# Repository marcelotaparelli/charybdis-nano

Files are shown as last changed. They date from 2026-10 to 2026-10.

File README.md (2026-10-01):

# Charybdis Nano 3x5 — documentação da build

Este repositório registra a construção completa de um Charybdis Nano 3x5: arquivos de impressão, arquitetura eletrônica, compras, montagem e configuração. A build é handwire, usa dois RP2040-Zero e QMK, e terá trackball óptico PMW3360 de 34 mm.

## Fluxo da build

**IMPRIMIR → COMPRAR → SOLDAR → MONTAR → CONFIGURAR QMK → USAR**

## Estrutura

- `01_cases/` — cases das duas metades.
- `02_bottom_plates/` — placas inferiores.
- `03_trackball/` — peças do conjunto da trackball.
- `04_tenting/` — peças para inclinação.
- `05_keycaps/` — coupon e conjunto de keycaps.
- `06_electronics/` — arquitetura, BOM, PCB do sensor e registro de compras.

> **Atenção:** os arquivos `LEFT` já estão espelhados. **Não espelhe novamente no slicer.** Há 11 modelos de impressão atualmente no repositório.

## Keycaps

O procedimento recomendado para builds em geral continua sendo imprimir primeiro `05_keycaps/MX_stem_fit_coupon.stl`, testar em um switch MX e só então imprimir `05_keycaps/full_set_35.3mf`.

Nesta build, Marcelo decidiu conscientemente imprimir o conjunto completo de uma vez porque o custo total da impressão é baixo. Se o encaixe exigir, os keycaps serão recalibrados e reimpressos. Essa é uma decisão específica desta build, não uma mudança na recomendação geral.

O conjunto tem quatro perfis ergonômicos, que não devem ser tratados como um único perfil: 10 top, 10 home, 10 bottom e 5 thumb.

## Eletrônica e andamento

A pasta [`06_electronics/`](06_electronics/README.md) documenta a arquitetura escolhida, a BOM viva, a placa PMW3360 rev 2.0c e os gastos confirmados. A ligação entre as metades ainda é uma hipótese: protocolo QMK split, pinout e quantidade de condutores precisam ser validados antes da soldagem final.

## Licenças

Créditos, origens conhecidas e termos das geometrias de terceiros estão em [`THIRD_PARTY_LICENSES.md`](THIRD_PARTY_LICENSES.md). As licenças aplicáveis continuam válidas.

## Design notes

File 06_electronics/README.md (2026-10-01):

# Eletrônica — Charybdis Nano 3x5

## Arquitetura escolhida

- Charybdis Nano 3x5, handwire, com switches MX e diodos through-hole 1N4148.
- Dois controladores RP2040-Zero com USB-C, um por metade, usando QMK.
- Sensor óptico PMW3360DM-T2QU com lente LM19-LSI e trackball de 34 mm.
- Três rolamentos MR63ZZ de 3 × 6 × 2,5 mm.
- Sem RGB, key flex PCBs, thumb flex PCB, Splinky ou Splinktegrated.

O handwire foi escolhido para dispensar PCBs flexíveis de matriz e permitir a montagem direta dos switches, diodos e controladores. A placa dedicada do sensor PMW3360 continua sendo usada. O pedido de fabricação dessa placa e sua montagem SMD estão descritos em [trackball-pcb.md](trackball-pcb.md).

## Controladores

São usados dois RP2040-Zero USB-C, um em cada metade. O holder do RP2040-Zero ainda não está resolvido; nenhum STL de holder foi definido. Antes de desenhar ou fabricar um adaptador, devem ser validados:

1. Dimensões reais do RP2040-Zero recebido.
2. Espaço interno disponível nos cases.
3. Pontos de montagem existentes.
4. Acesso e orientação do USB-C.
5. Folga para fios e solda.

A preferência futura é por um pequeno holder/adaptador independente, sem modificar os STLs originais dos cases.

## Ligação entre as metades

A intenção atual é evitar TRRS na primeira build e usar uma ligação fixa simples. **VCC + GND + DATA é apenas uma hipótese atual, não uma solução elétrica fechada ou validada.** O protocolo QMK split, o pinout e a quantidade de condutores ainda precisam ser definidos e validados antes da soldagem final. A interligação entre as metades ainda não foi testada eletricamente.

## Próximas etapas físicas

1. Receber e inspecionar a impressão.
2. Comprar os componentes restantes.
3. Receber as PCBs PMW3360.
4. Validar os encaixes.
5. Resolver o holder do RP2040-Zero.
6. Fazer o handwire da matriz.
7. Montar o sensor e a trackball.
8. Configurar QMK.

Consulte a [BOM viva](bom.md) para itens e status e o [registro de compras](purchases.md) para valores efetivamente pagos.

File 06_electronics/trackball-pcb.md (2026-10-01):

# PCB da trackball — PMW3360 rev 2.0c

## Projeto e arquivos usados

Projeto oficial: [BastardKB/charybdis-pmw-3360-sensor-pcb](https://github.com/Bastardkb/charybdis-pmw-3360-sensor-pcb)

Release correta: [2.0c](https://github.com/Bastardkb/charybdis-pmw-3360-sensor-pcb/releases/tag/2.0c)

Arquivos exatos utilizados no pedido:

- Gerber: [`sensor_2.0c.zip`](https://github.com/Bastardkb/charybdis-pmw-3360-sensor-pcb/releases/download/2.0c/sensor_2.0c.zip)
- BOM: [`bom.csv`](https://github.com/Bastardkb/charybdis-pmw-3360-sensor-pcb/releases/download/2.0c/bom.csv)
- Positions/CPL: [`positions.csv`](https://github.com/Bastardkb/charybdis-pmw-3360-sensor-pcb/releases/download/2.0c/positions.csv)

Os arquivos de fabricação não foram copiados para este repositório; use os assets da release oficial indicada.

## Alerta sobre o Gerber

**Não use como Gerber desta build `sensor/jlcpcb/production_files/GERBER-sensor.zip`.** Durante a preparação do pedido, esse pacote antigo foi conferido e renderizava **REV 1.8**. Com o BOM/CPL 2.0c, os componentes apareciam visualmente deslocados. O pedido foi interrompido antes da fabricação. A correção foi usar o asset `sensor_2.0c.zip` da release oficial 2.0c.

Antes de pagar, o preview final do pedido com o Gerber correto foi revisado; os overlays dos componentes estavam alinhados com os pads.

## Configuração registrada do pedido JLCPCB

**PCB**

- FR-4, 2 layers, espessura 1,6 mm, cobre 1 oz.
- Máscara verde e serigrafia branca.
- HASL.
- Quantidade: 5 PCBs.

**PCBA**

- Economic PCBA, Bottom Side.
- Quantidade: 2 placas montadas.
- Parts Selection / Self-Service.
- A montagem automática inclui os componentes SMD selecionados no BOM/CPL.

Itens deliberadamente fora da montagem de fábrica:

- **U1001 — PMW3360DM-T2QU:** será comprado e montado separadamente; não incluso na PCBA.
- **J1001 — header 1 × 06, 2,54 mm:** não precisa ser montado pela fábrica.
- **J1002 — conector FPC:** não selecionado, pois a build é handwire e não usa o flex correspondente.
- **LM19-LSI:** lente óptica/mecânica, será comprada separadamente.

O pedido foi pago. Valores finais e totais por moeda estão em [purchases.md](purchases.md).

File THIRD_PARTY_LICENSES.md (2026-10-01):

# Atribuição e licenças de terceiros

Este pacote reúne geometrias de terceiros e versões espelhadas. Os créditos e termos dos projetos de origem continuam aplicáveis.

## Charybdis

- Projeto: [BastardKB/Charybdis](https://github.com/Bastardkb/Charybdis)
- Licença: CC BY-NC-SA 4.0

Arquivos originados ou derivados desse projeto:

- `01_cases/RIGHT_charybdisnano_v2_v187.stl`
- `02_bottom_plates/RIGHT_alien_v2_185.stl`
- `03_trackball/adapter_v2_top_v75.stl`
- `03_trackball/adapter_v4_bottom_v17.stl`
- `03_trackball/sensor_cover_v51.stl`
- `04_tenting/RIGHT_tent15deg_v2_27.stl`
- `04_tenting/LEFT_tent15deg_v2_27.stl` — versão espelhada no eixo X do tent correspondente.

## Skeletyl

- Projeto: [BastardKB/Skeletyl](https://github.com/Bastardkb/Skeletyl)
- Licença: CC BY-NC-SA 4.0

Arquivos originados ou derivados desse projeto:

- `01_cases/LEFT_case_v4_103.stl` — versão espelhada no eixo X da geometria Skeletyl V4 correspondente.
- `02_bottom_plates/LEFT_plate_v4_103.stl` — versão espelhada no eixo X da geometria Skeletyl V4 correspondente.

Não há reivindicação de autoria sobre as geometrias originais. Os termos de uso não comercial (NC) e compartilhamento pela mesma licença (SA) continuam aplicáveis às derivações.

## DES / PseudoMakeMeKeyCapProfiles

- Projeto: [pseudoku/PseudoMakeMeKeyCapProfiles](https://github.com/pseudoku/PseudoMakeMeKeyCapProfiles)
- Licença: GPL-3.0

Arquivos relacionados:

- `05_keycaps/MX_stem_fit_coupon.stl`
- `05_keycaps/full_set_35.3mf`
- `05_keycaps/source/des_compatible_keycaps.scad`
- `05_keycaps/source/mx_stem_fit_coupon.scad`
- `05_keycaps/source/plates.scad`

Texto da licença em `LICENSES/GPL-3.0.txt`.

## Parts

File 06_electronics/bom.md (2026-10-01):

# BOM — lista de materiais viva

Os status e preços abaixo registram apenas informações confirmadas. “A comprar” indica que não há compra confirmada nesta documentação; preço e fornecedor permanecem em aberto.

| Peça | Modelo / especificação | Qtd. | Status | Preço pago | Fornecedor / link |
|---|---|---:|---|---:|---|
| Controlador | RP2040-Zero USB-C | 2× | Comprado | R$ 55,76 total pago | [WJ Componentes](https://www.wjcomponentes.com.br/placa-desenvolvimento-rp2040-zero-usb-c) |
| Switches | Outemu Red, MX, linear | 40 comprados; 35 usados + 5 reservas | Comprado | R$ 89,99 | Mercado Livre |
| Diodos | 1N4148, axial / through-hole, DO-35 | 100 comprados; ~35 usados + restante reserva | Comprado | R$ 20,00 | Mercado Livre |
| Sensor | PMW3360DM-T2QU | 1 | Comprado | R$ 91,75 total do conjunto | AliExpress |
| Lente | LM19-LSI | 1 | Comprada | Incluída no conjunto (total na linha do sensor) | AliExpress |
| PCB do sensor | BastardKB PMW3360, rev 2.0c | 5 fabricadas; 2 com PCBA | Comprado; pedido pago | US$ 23.54 (pedido inteiro; não é preço unitário) | [Release oficial 2.0c](https://github.com/Bastardkb/charybdis-pmw-3360-sensor-pcb/releases/tag/2.0c); JLCPCB |
| Fio para handwire | 28 AWG / aproximadamente 0,10 mm² | 1 rolo | Comprado | R$ 50,96 | Mercado Livre |
| Cabo | USB-C com dados | A definir | A comprar | — | A definir |
| Trackball | Esfera de 34 mm, compatível com Logitech M570/M575 | 1 | Comprado | R$ 94,00 total | Mercado Livre |
| Rolamentos | MR63ZZ, 3 × 6 × 2,5 mm | 4 comprados; 3 usados + 1 reserva | Comprado | R$ 54,96 total (produto R$ 47,90) | [Mercado Livre](https://www.mercadolivre.com.br/4-rolamentos-mr63zz-3mm--6mm--25mm-micro-rolamento/up/MLBU597514219) |
| Parafusos | M4 × 8 | 12 | A comprar | — | A definir |
| Insertos | M4 × D6,0 × L5,0 | 12 | A comprar | — | A definir |
| Parafusos | M3 × 8 | 8 | A comprar | — | A definir |
| Insertos | M3 × D5 × L5 | 5 | A comprar | — | A definir |
| Pés | Pés de borracha, opcionais | A definir | A comprar (opcional) | — | A definir |

## Ferramentas, caso ainda não estejam disponíveis

| Ferramenta | Qtd. | Status | Preço pago | Fornecedor / link |
|---|---:|---|---:|---|
| Ferro de solda | 1 | Verificar disponibilidade | — | A definir |
| Suporte para ferro | 1 | Verificar disponibilidade | — | A definir |
| Solda | A definir | Verificar disponibilidade | — | A definir |
| Fluxo | A definir | Verificar disponibilidade | — | A definir |
| Multímetro com continuidade | 1 | Verificar disponibilidade | — | A definir |
| Alicate de corte rente | 1 | Verificar disponibilidade | — | A definir |
| Pinça | 1 | Verificar disponibilidade | — | A definir |
| Sugador de solda | 1 | Recomendado; verificar disponibilidade | — | A definir |

Os componentes SMD definidos no BOM/CPL usados no pedido da placa foram selecionados para montagem pela fábrica nas duas PCBs. O sensor U1001, a lente e os conectores excluídos dessa montagem estão discriminados em [trackball-pcb.md](trackball-pcb.md).

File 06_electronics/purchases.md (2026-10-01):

# Registro de compras e custos

Este registro contém valores informados como efetivamente pagos ou contratados. Totais são mantidos separados por moeda; não há conversão de USD para BRL porque a conversão efetivamente aplicada na cobrança não está registrada.

## Compra 1 — impressão

- **Data:** 2026-10-01
- **Fornecedor:** Nutss
- **Site:** [nutss3d.com.br](https://nutss3d.com.br/)
- **Escopo:** impressão de todo o projeto, incluindo keycaps em resina.
- **Valor combinado/pago:** R$ 195,00.
- **Status:** contratado; produção pendente ou iniciando.

Marcelo decidiu, como exceção consciente desta build, imprimir o conjunto completo de keycaps antes de validar o coupon. O custo total da impressão é baixo para esta build e, se o encaixe exigir, os keycaps serão recalibrados e reimpressos. Isso não altera o procedimento recomendado geral: imprimir e testar o coupon MX antes do conjunto completo.

## Compra 2 — JLCPCB

- **Status:** pago.
- **Item:** PCB do sensor PMW3360 rev 2.0c.
- **Quantidade:** 5 PCBs; PCBA Bottom Side em 2 placas.
- **Serviço de envio:** Global Standard Direct Line.
- **Merchandise Total:** US$ 12.13.
- **Shipping:** US$ 11.41.
- **Order Total pago:** **US$ 23.54**.

US$ 22.13 não é o valor pago: houve desconto antes do fechamento do pedido. A composição e as exclusões da montagem estão em [trackball-pcb.md](trackball-pcb.md).

## Compra 3 — rolamentos MR63ZZ

- **Data:** 2026-10-01
- **Fornecedor:** Mercado Livre
- **Item:** 4× MR63ZZ, 3 × 6 × 2,5 mm.
- **Uso:** 3 necessários + 1 reserva.
- **Produto:** R$ 47,90.
- **Frete:** grátis.
- **Total informado/pago:** R$ 54,96.
- **Status:** comprado.
- **Anúncio:** [4 rolamentos MR63ZZ](https://www.mercadolivre.com.br/4-rolamentos-mr63zz-3mm--6mm--25mm-micro-rolamento/up/MLBU597514219).

## Compra 4 — esfera do trackball

- **Data:** 2026-10-01
- **Fornecedor:** Mercado Livre
- **Item:** esfera de trackball de 34 mm, compatível com Logitech M570/M575.
- **Produto:** R$ 54,03.
- **Frete:** R$ 23,99.
- **Impostos:** R$ 15,98.
- **Total pago:** R$ 94,00.
- **Status:** comprado.

## Compra 5 — sensor PMW3360DM-T2QU + lente LM19-LSI

- **Data:** 2026-10-01
- **Fornecedor:** AliExpress
- **Itens:** PMW3360DM-T2QU e lente LM19-LSI, vendidos como conjunto.
- **Subtotal:** R$ 48,99.
- **Frete:** R$ 27,12.
- **Imposto de importação:** R$ 0,00.
- **ICMS:** R$ 15,64.
- **Total pago:** R$ 91,75.
- **Status:** pago/comprado.

O valor de R$ 91,75 corresponde ao conjunto e não está dividido entre sensor e lente.

## Compra 6 — controladoras RP2040-Zero

- **Data:** 2026-10-01
- **Fornecedor:** WJ Componentes Eletrônicos
- **Item:** RP2040-Zero USB-C.
- **Quantidade:** 2.
- **Preço nominal por unidade:** R$ 23,51.
- **Subtotal dos produtos:** R$ 47,02.
- **Frete:** Sedex Correios, R$ 10,15.
- **Total normal do pedido:** R$ 57,17.
- **Total efetivamente pago no Pix com desconto:** R$ 55,76.
- **Status:** comprado/pago.
- **Produto:** [Placa de desenvolvimento RP2040 Zero USB-C](https://www.wjcomponentes.com.br/placa-desenvolvimento-rp2040-zero-usb-c).

## Compra 7 — switches Outemu Red

- **Data:** 2026-10-01
- **Fornecedor:** Mercado Livre
- **Item:** switches Outemu Red, padrão MX, tipo linear.
- **Quantidade:** 40.
- **Uso previsto:** 35 usados + 5 de reserva.
- **Valor pago:** R$ 89,99.
- **Frete:** grátis.
- **Status:** comprado/pago.

## Compra 8 — diodos 1N4148

- **Data:** 2026-10-01
- **Fornecedor:** Mercado Livre
- **Item:** diodos 1N4148, encapsulamento DO-35, axial / through-hole.
- **Quantidade:** 100.
- **Quantidade necessária para a build:** aproximadamente 35; restante para reserva.
- **Total efetivamente pago:** R$ 20,00.
- **Status:** comprado/pago.

## Compra 9 — fio para handwire

- **Data:** 2026-10-01
- **Fornecedor:** Mercado Livre
- **Item:** fio para handwire, bitola 28 AWG, seção aproximada de 0,10 mm².
- **Quantidade:** 1 rolo.
- **Total efetivamente pago:** R$ 50,96.
- **Status:** comprado/pago.

## Total acumulado confirmado

- **BRL:** R$ 652,42.
- **USD:** US$ 23.54.

Os montantes permanecem em moedas separadas. Não converter USD para BRL sem o valor efetivo da conversão aplicada na cobrança.

## Próximas compras

Consultar a [BOM](bom.md) para a relação atual de componentes, hardware e ferramentas a comprar ou verificar. Não há preço ou fornecedor confirmado para os itens ainda não adquiridos.

Para cada compra futura, registrar item exato, quantidade, preço pago, frete, fornecedor, link, data e status de entrega.

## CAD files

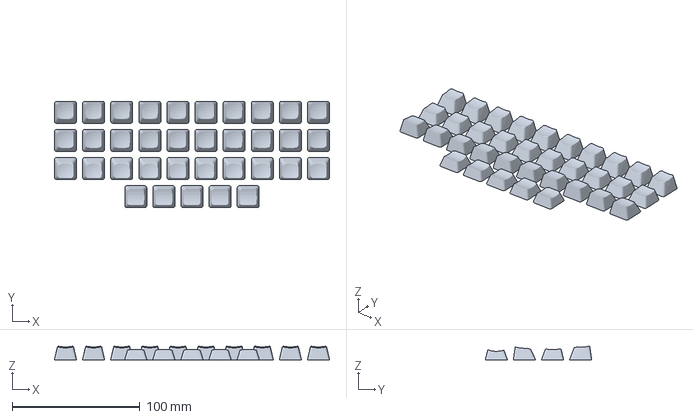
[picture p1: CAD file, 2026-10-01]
05_keycaps/full_set_35.3mf
215.2 x 83.2 x 10.6 mm

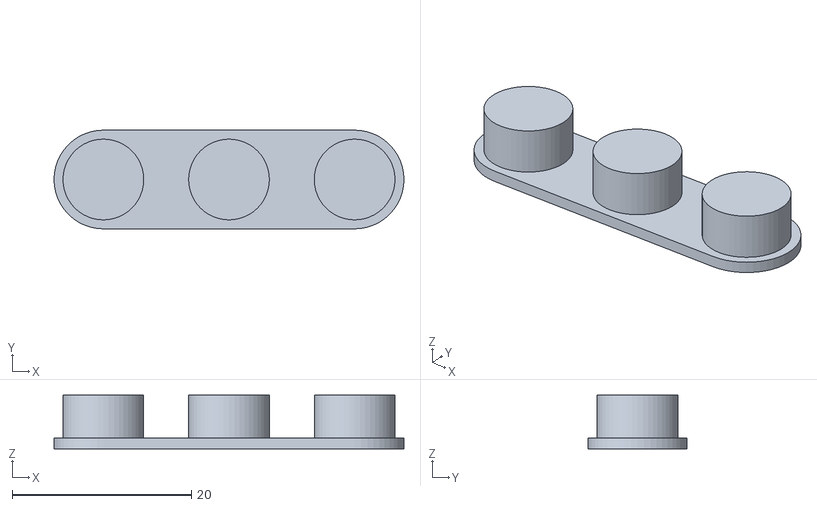
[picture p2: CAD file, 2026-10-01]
05_keycaps/MX_stem_fit_coupon.stl
39.0 x 11.0 x 6.00

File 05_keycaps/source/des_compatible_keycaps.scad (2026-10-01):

$fn=64;
profile="top";

module rr2d(w,d,r){ offset(r=r) square([w-2*r,d-2*r],center=true); }
module slab(w,d,r,z,shift=0,ang=0,t=0.35){
  translate([0,shift,z]) rotate([ang,0,0]) linear_extrude(height=t,center=true) rr2d(w,d,r);
}
module frustum(bw,bd,tw,td,br,tr,h,shift,ang){
  hull(){ slab(bw,bd,br,0.2,0,0,0.4); slab(tw,td,tr,h-0.2,shift,ang,0.4); }
}
module cross_slot(len=4.25,th=1.35,h=5){
 union(){cube([len,th,h],center=true); cube([th,len,h],center=true);} }
module keycap(h=10.5,ang=9,shift=1.1,dish=1.5,saddle=false){
  bw=17.2; bd=17.2; tw=12.2; td=12.2;
  wall=1.7; topth=2.0;
  difference(){
    union(){
      difference(){
        frustum(bw,bd,tw,td,1.6,2.0,h,shift,ang);
        translate([0,0,-0.4]) frustum(bw-2*wall,bd-2*wall,tw-2*wall,td-2*wall,1.0,1.3,h-topth+0.6,shift*0.72,ang*0.72);
      }
      // MX stem boss attached to roof
      cylinder(d=6.6,h=h-topth+0.7);
    }
    // dish cut
    if(saddle){
      translate([0,0,h+18-dish]) rotate([0,90,0]) cylinder(r=18,h=40,center=true);
    } else {
      translate([0,0,h+24-dish]) sphere(r=24);
    }
    // female MX cross
    translate([0,0,2.0]) cross_slot(4.25,1.35,4.6);
  }
}
if(profile=="top") keycap(h=10.55,ang=9,shift=1.0,dish=1.6);
if(profile=="home") keycap(h=8.75,ang=4,shift=.5,dish=1.7);
if(profile=="bottom") keycap(h=9.75,ang=-13,shift=-1.2,dish=1.6);
if(profile=="thumb") keycap(h=8.4,ang=-3,shift=-.3,dish=1.8,saddle=true);

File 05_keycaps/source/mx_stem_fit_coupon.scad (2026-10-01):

$fn=48;
module cross_slot(len,th,h=5){union(){cube([len,th,h],center=true);cube([th,len,h],center=true);}}
module test(x,tol){
  translate([x,0,0]) difference(){
    cylinder(d=9,h=6);
    translate([0,0,2.4]) cross_slot(4.03+2*tol,1.15+2*tol,5);
  }
}
hull(){translate([-14,0,0]) cylinder(d=11,h=1.2); translate([14,0,0]) cylinder(d=11,h=1.2);}
test(-14,0.05); test(0,0.10); test(14,0.15);

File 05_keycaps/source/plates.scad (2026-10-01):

set = "full";
pitch=22;
module cap(file,x,y){ translate([x,y,0]) import(file); }
module row(file,n,y){ for(i=[0:n-1]) cap(file,(i-(n-1)/2)*pitch,y); }
module top10(){ row("../masters/DES_top.stl",10,0); }
module home10(){ row("../masters/DES_home.stl",10,0); }
module bottom10(){ row("../masters/DES_bottom.stl",10,0); }
module thumb5(){ row("../masters/DES_thumb.stl",5,0); }
module full35(){
 row("../masters/DES_top.stl",10,33);
 row("../masters/DES_home.stl",10,11);
 row("../masters/DES_bottom.stl",10,-11);
 row("../masters/DES_thumb.stl",5,-33);
}
if(set=="top10") top10();
if(set=="home10") home10();
if(set=="bottom10") bottom10();
if(set=="thumb5") thumb5();
if(set=="full") full35();

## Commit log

2026-10-01 feat: upload files
    [DES_bottom.3mf, DES_bottom.stl, DES_home.3mf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]
2026-10-01 feat: add mirrored left STLs and licenses
    [LEFT_case_v4_103.stl, LEFT_plate_v4_103.stl, LEFT_tent15deg_v2_27.stl]
2026-10-01 feat: add print-ready Charybdis Nano files
    [LEFT_case_v4_103.stl, LEFT_plate_v4_103.stl, LEFT_tent15deg_v2_27.stl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]
2026-10-01 chore: clean repo into print-ready package, keep 11 models and licenses
    [DES_bottom.3mf, DES_bottom.stl, DES_home.3mf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]
2026-10-01 docs: record MR63ZZ bearing purchase
2026-10-01 docs: record 34mm trackball purchase
2026-10-01 docs: record trackball sensor purchases
2026-10-01 docs: record Outemu Red switch purchase
2026-10-01 docs: record 1N4148 diode purchase
